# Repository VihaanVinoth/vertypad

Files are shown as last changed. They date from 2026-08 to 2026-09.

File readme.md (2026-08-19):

# VertyPad

The **VertyPad** is a custom 4x2 matrix mechanical macropad, featuring a rotary encoder, and a 0.91-inch OLED screen. It is built with the Seeed Studio XIAO RP2040 microcontroller, powered by QMK, and supports **cross-platform switching (macOS and Windows)** with an **interactive OLED UI menu**.

### PCB
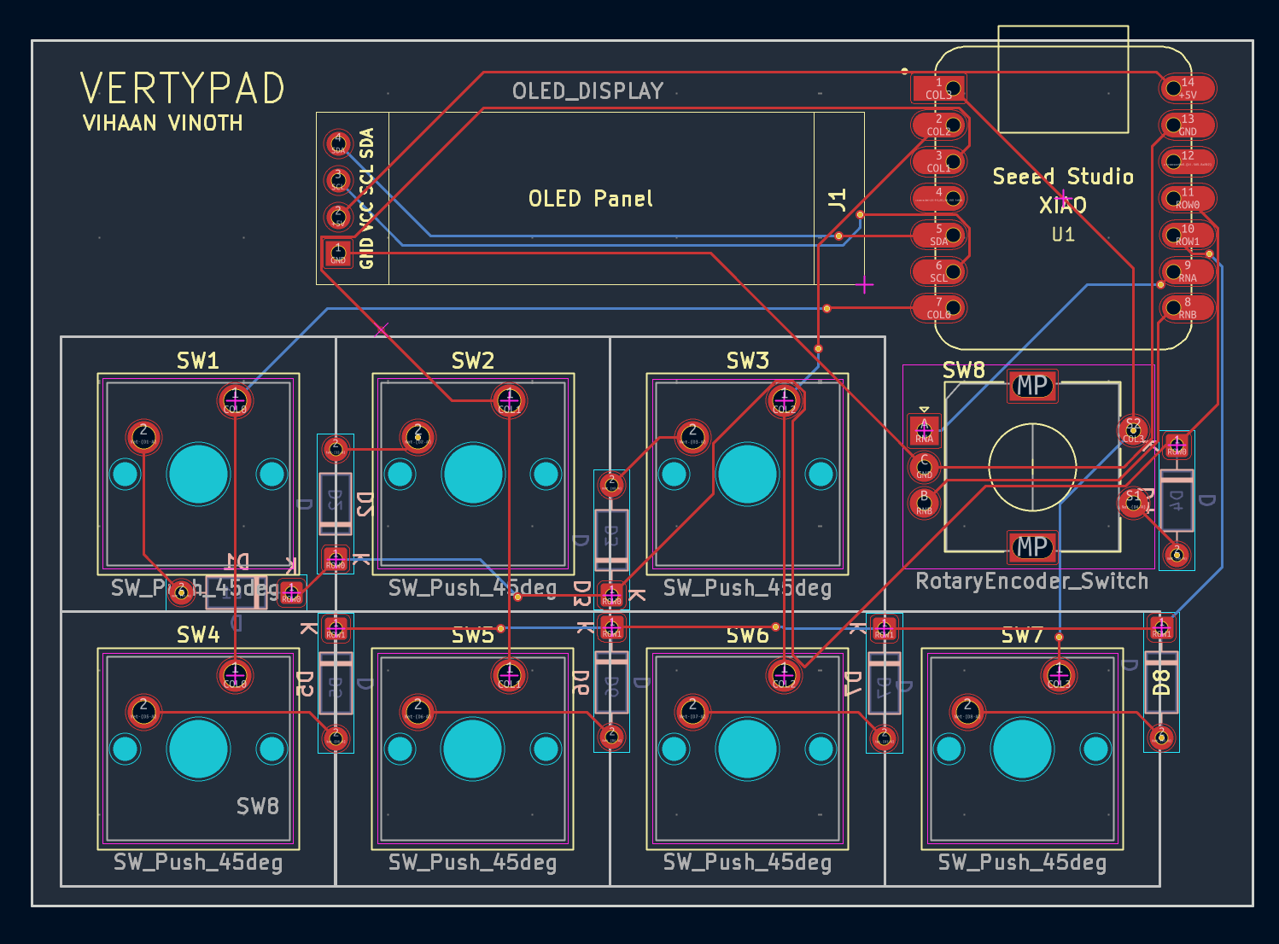
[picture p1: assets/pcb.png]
VertyPad PCB Trace Routing


### Schematics
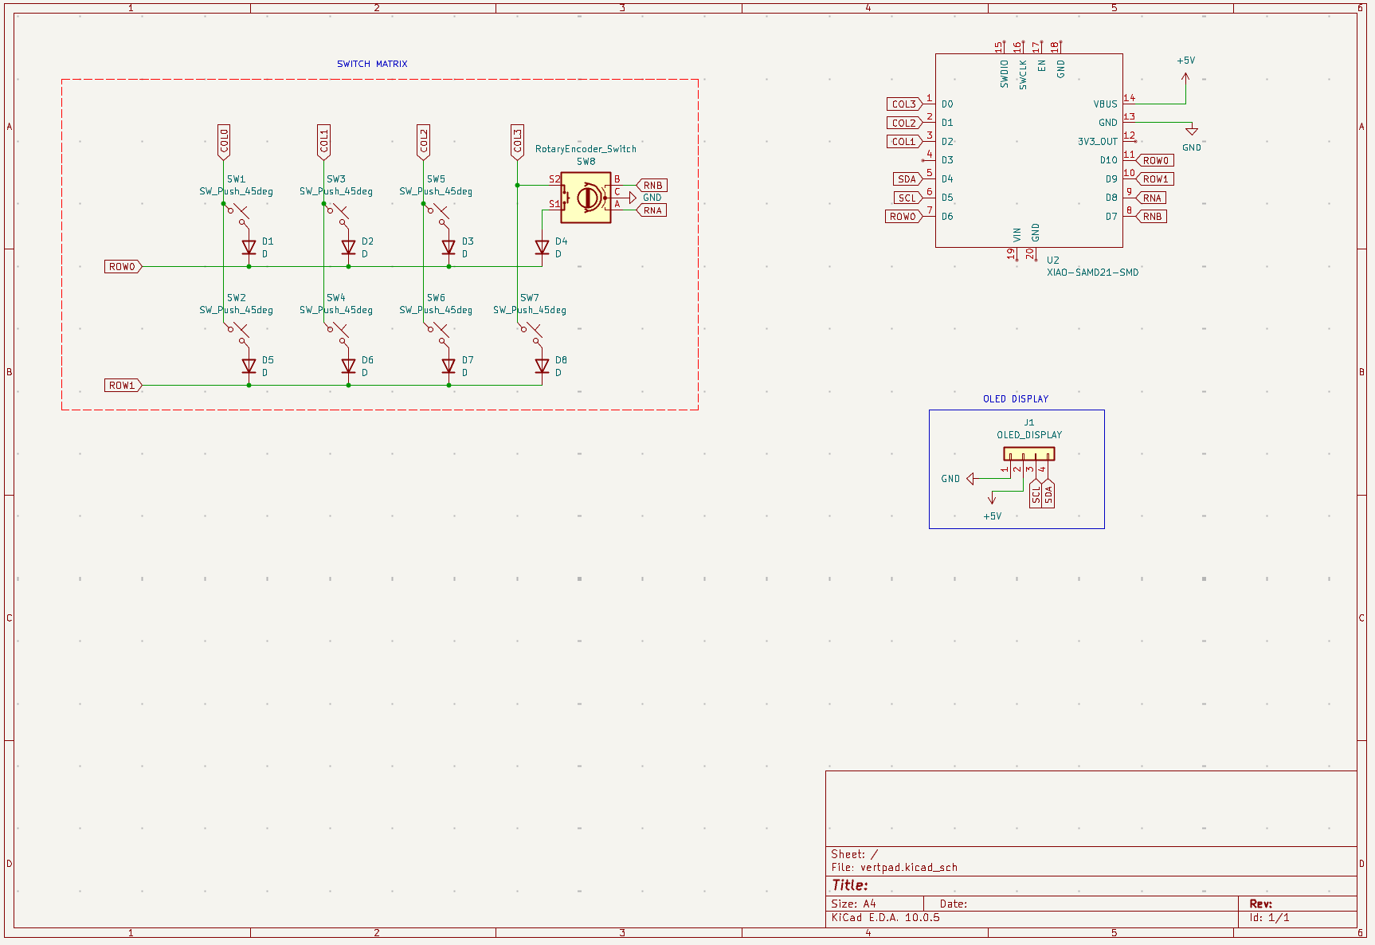
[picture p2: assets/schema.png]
VertyPad Matrix Schematic Map


### CAD
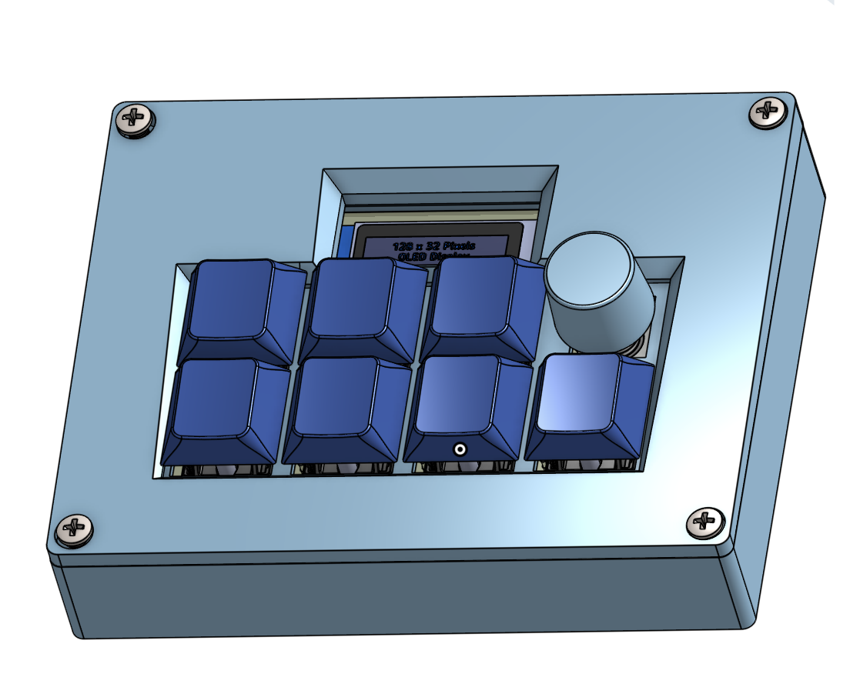
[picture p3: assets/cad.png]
VertyPad CAD


## BOM

| Component Type | Part Description | Quantity |
| :--- | :--- | :--- |
| **Microcontroller** | Seeed Studio XIAO RP2040 | 1 |
| **Switches** | Cherry MX-Style Mechanical Switches | 7 |
| **Rotary Encoder** | EC11 Rotary Encoder with Switch | 1 | 
| **Diodes** | 1N4148 Through-Hole Signal Diodes | 8 |
| **Display Panel** | 0.91-inch I2C Monochromatic OLED | 1 | 
| **Keycaps** | DSA Profile Blank Keycaps | 7 | 
| **Screws**| M3 x 16mm Screws | 4 | 
| **Case** | 3D Printed Case/Plate | 1 |
| **PCB** | A PCB | 1 |

## Keymap & Feature Profiles

The VertyPad supports various macro commands across MacOS and Windows:

* **Copy:** `Command + C` (macOS) or `Control + C` (Windows).
* **Paste:** `Command + V` (macOS) or `Control + V` (Windows).
* **Spotlight/Search:** Launches Apple Spotlight Search (`Cmd + Space`) or Windows Search (`Win + S`).
* **Lock:** Locks the screen (`Cmd + Ctrl + Q` on Mac, `Win + L` on Windows).
* **Standard Keycodes:** Standard layout keycodes (`KC_4` and `KC_6`).
* **UI Select** Interactively toggles configuration states, such as switching between macOS and Windows modes on the OLED screen.
* **Rotary Dial Turn:** Cycles forward and backward through the **OLED UI menu screens** (Dashboard, OS Config, and Hardware Status).
* **Encoder Click Button (SW8):** Instant system audio stream mute toggle (`KC_MUTE`).

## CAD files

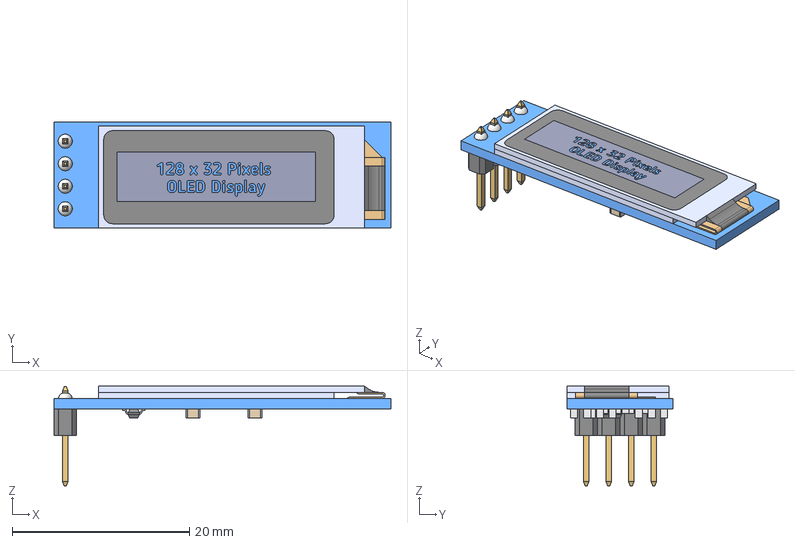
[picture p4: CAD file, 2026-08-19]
production/3D Models/OLED 128 x 32 Display Assembly.step
38.0 x 12.0 x 11.3 mm
Board_001
1x4 Male Header_001
0603 Capacitor_001
0603 Capacitor_002
0603 Capacitor_003
0603 Capacitor_004
0603 Capacitor_005
0603 Capacitor_006
0603 Capacitor_007
0603 Capacitor_008
0603 Resistor_001
0603 Resistor_002
0603 Resistor_003
0603 Resistor_004
0603 Resistor_005
Surface Mount Transistor_001

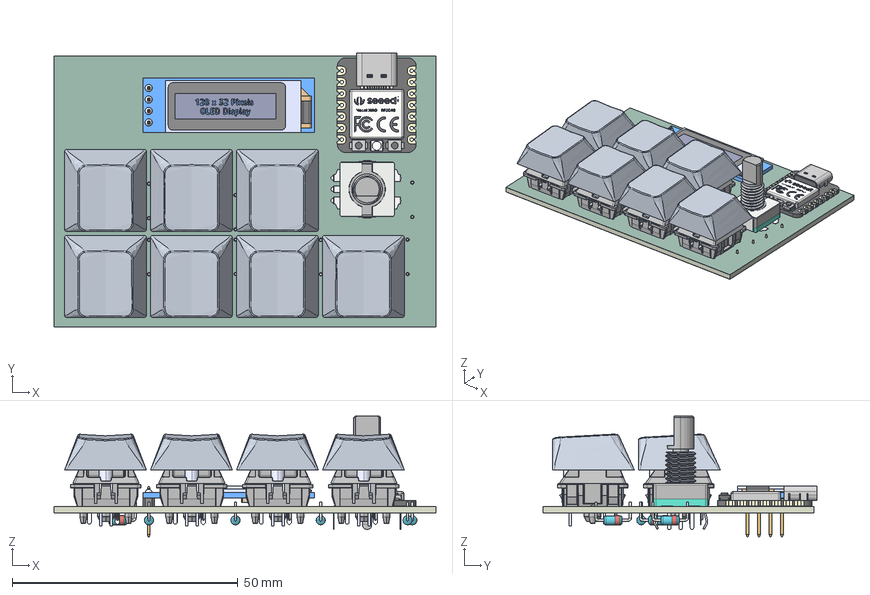
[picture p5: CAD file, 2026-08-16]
pcb/vertpad.step
84.6 x 60.6 x 26.8 mm
MX Öá °´¼ü¡ä_¨¹___¡§1 x 7
MX ס סͥ¨¢¨¬_¡§¡顧__ x 7
MXס ϞñLEDLEDLED x 7
MXÖá ÖáÌå µ×²¿ ¦Ì¡Á2__Ä¬ÈÏ_¨¢2____¨¨_ x 7
֫½ğ__Ĭɏ__¨¨_ x 7
r2_100 x 7
Board_001
1x4 Male Header_001
0603 Capacitor_001
0603 Capacitor_002
0603 Capacitor_003
0603 Capacitor_004
0603 Capacitor_005
0603 Capacitor_006
0603 Capacitor_007
0603 Capacitor_008
0603 Resistor_001
0603 Resistor_002
0603 Resistor_003
0603 Resistor_004
0603 Resistor_005
Surface Mount Transistor_001
ѽת±ძǷ
type-c v2
smd_button v3
DOUT
DIN
VSS
VDD
smd_button v3(Mirror)
D_DO-35_SOD27_P7.62mm_Horizontal x 8
vertpad_soldermask x 2
vertpad_PCB

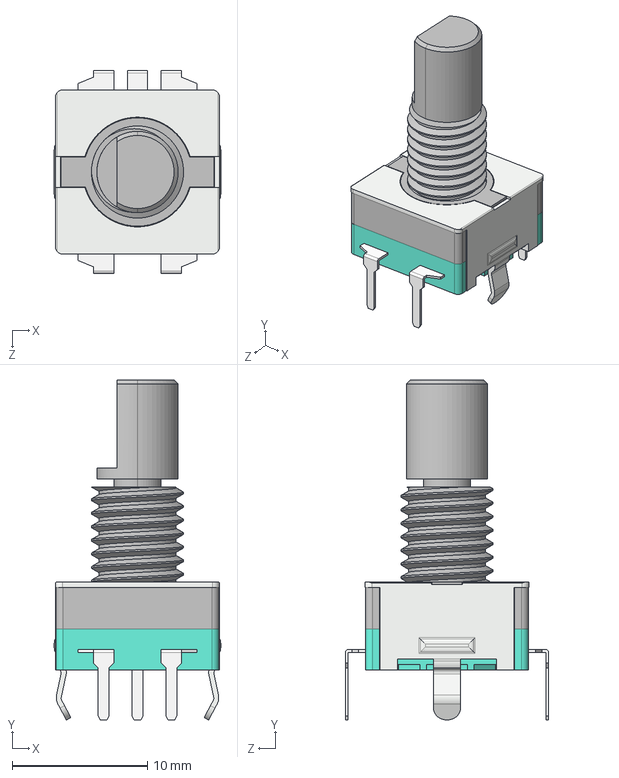
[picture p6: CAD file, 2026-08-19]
production/3D Models/encoder.step
12.3 x 25.1 x 15.0 mm

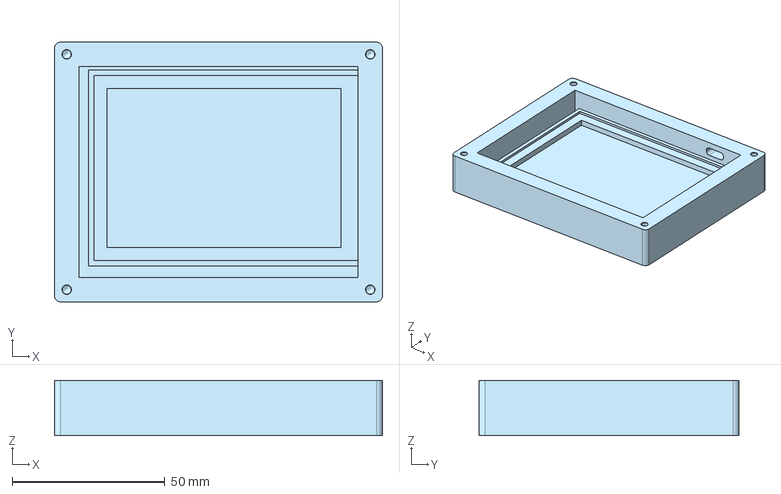
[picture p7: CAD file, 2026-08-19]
production/case.step
107.3 x 85.0 x 18.0 mm

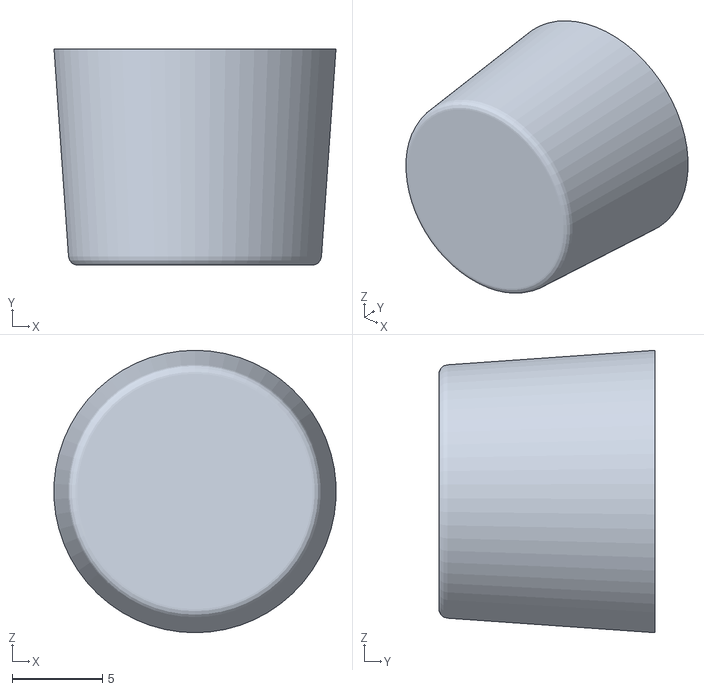
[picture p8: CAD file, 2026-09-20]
production/prints/knob.stl
15.7 x 12.0 x 15.7

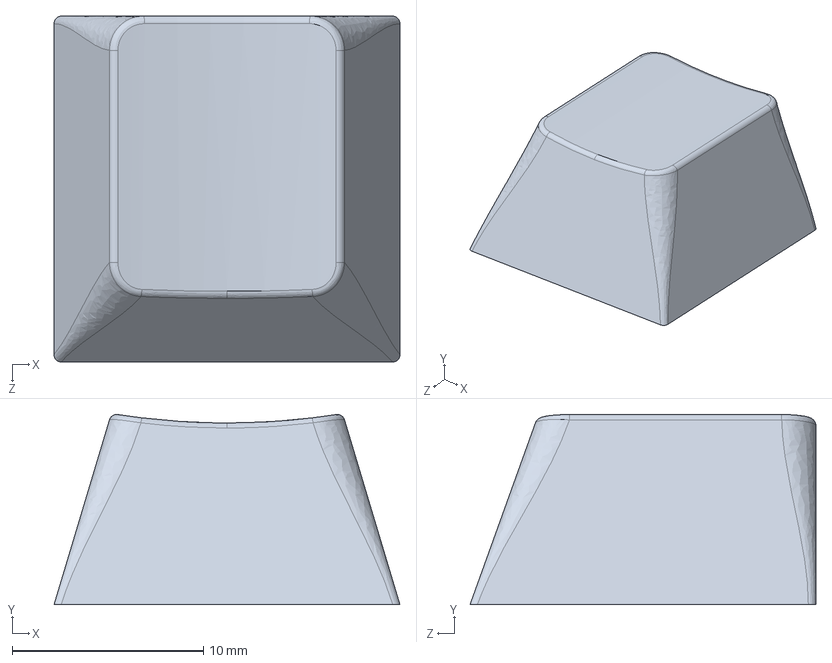
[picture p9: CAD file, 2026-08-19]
production/3D Models/r1_100.STEP
18.1 x 9.95 x 18.1 mm

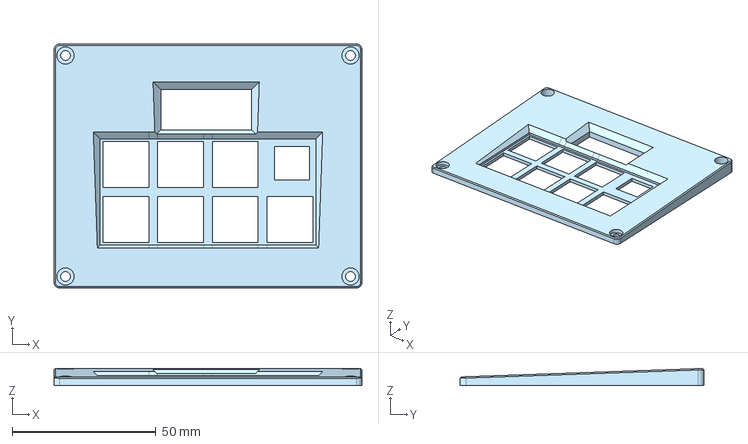
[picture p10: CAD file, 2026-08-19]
production/plate.step
107.3 x 85.0 x 5.95 mm

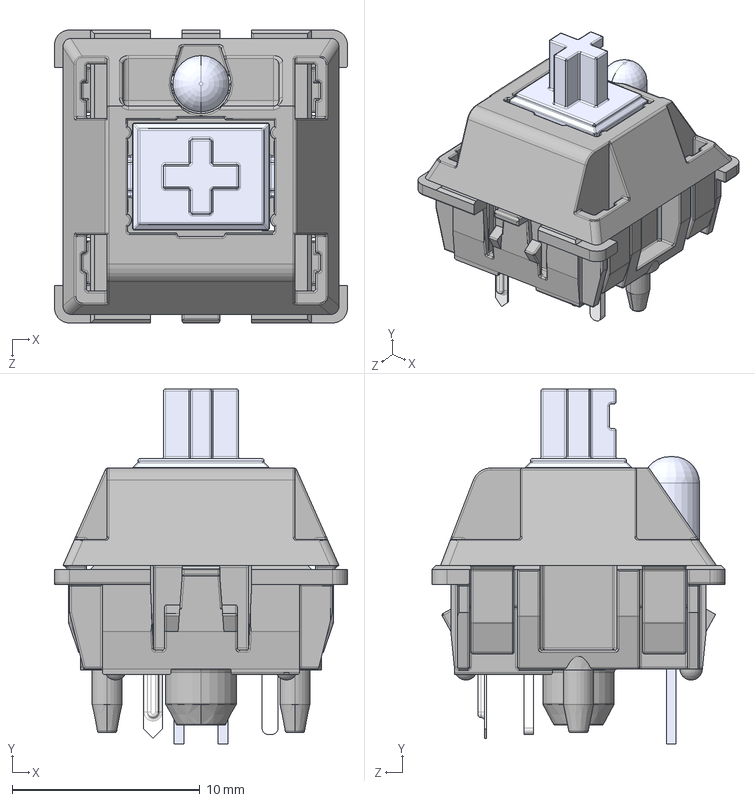
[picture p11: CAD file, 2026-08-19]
production/3D Models/mx.step
15.6 x 18.9 x 15.6 mm
MX 轴 按键′_ü___¨1
MX 轴 轴体áì_¨￠¨__
MX粣 拸簽LEDLEDLED
MX轴 轴体 底部 μ×2__默认_á2____è_
针脚___默认__è_

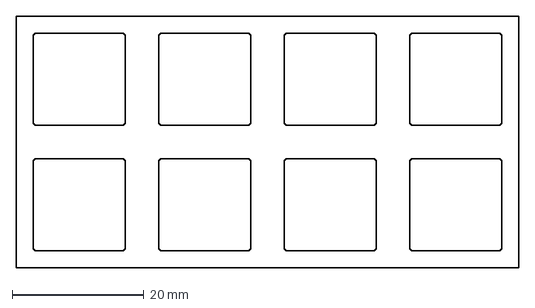
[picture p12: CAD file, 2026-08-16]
production/plate-2026-08-08T04_57_57.347Z.dxf
76.2 x 38.1 mm

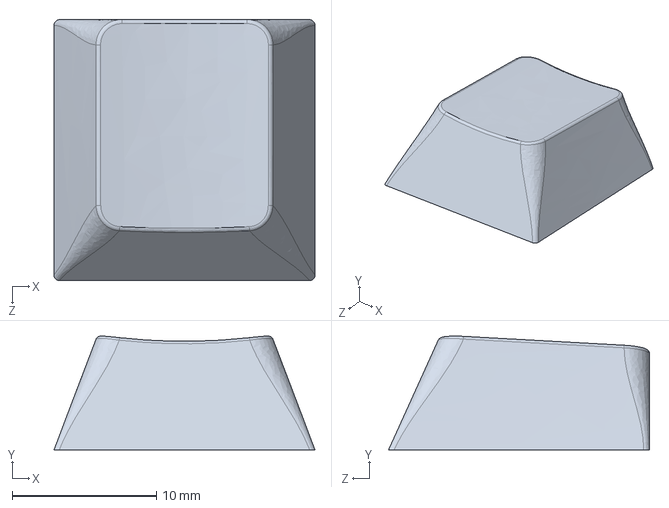
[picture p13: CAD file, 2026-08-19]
production/3D Models/r2_100.STEP
18.1 x 7.89 x 18.1 mm

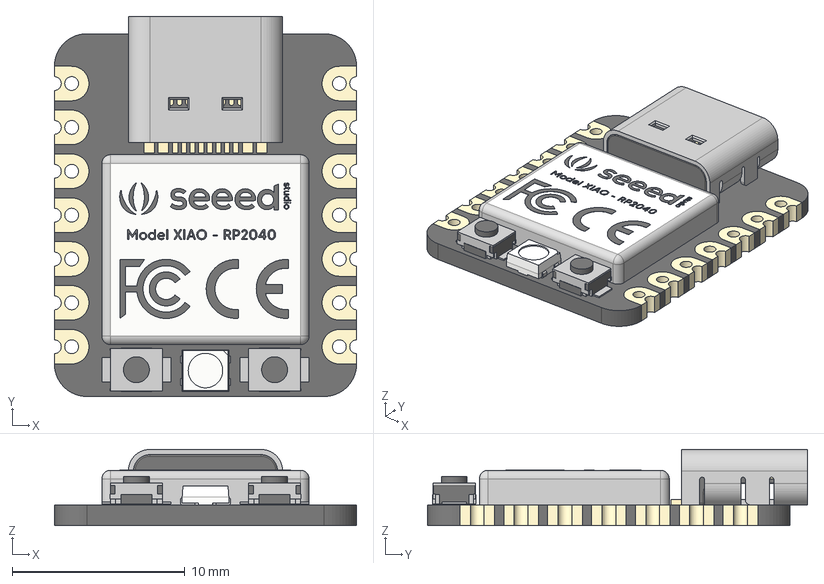
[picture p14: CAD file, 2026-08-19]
production/3D Models/Seeed Studio XIAO RP2040 v26.step
17.5 x 22.0 x 4.40 mm
type-c v2
smd_button v3
DOUT
DIN
VSS
VDD
smd_button v3(Mirror)

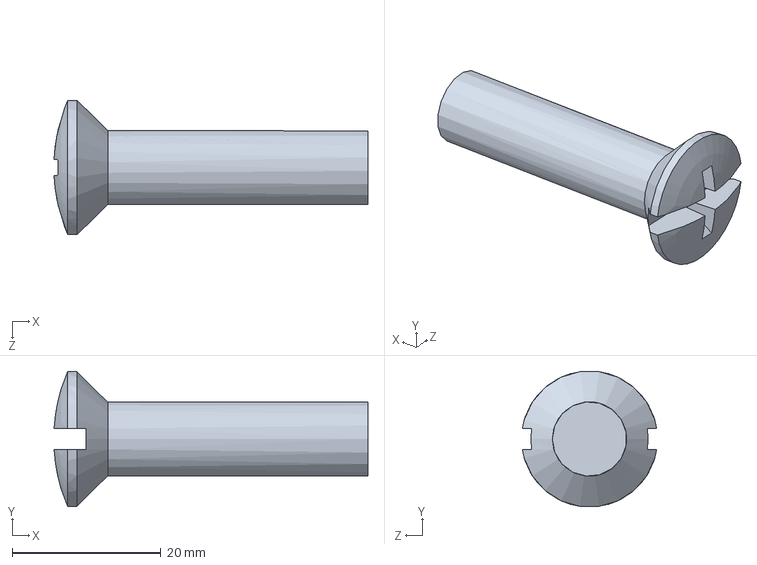
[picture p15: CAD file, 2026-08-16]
production/3D Models/m3-16mm.sldprt
42.2 x 18.2 x 18.1 mm

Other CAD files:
production/prints/case.stl
production/prints/plate.stl

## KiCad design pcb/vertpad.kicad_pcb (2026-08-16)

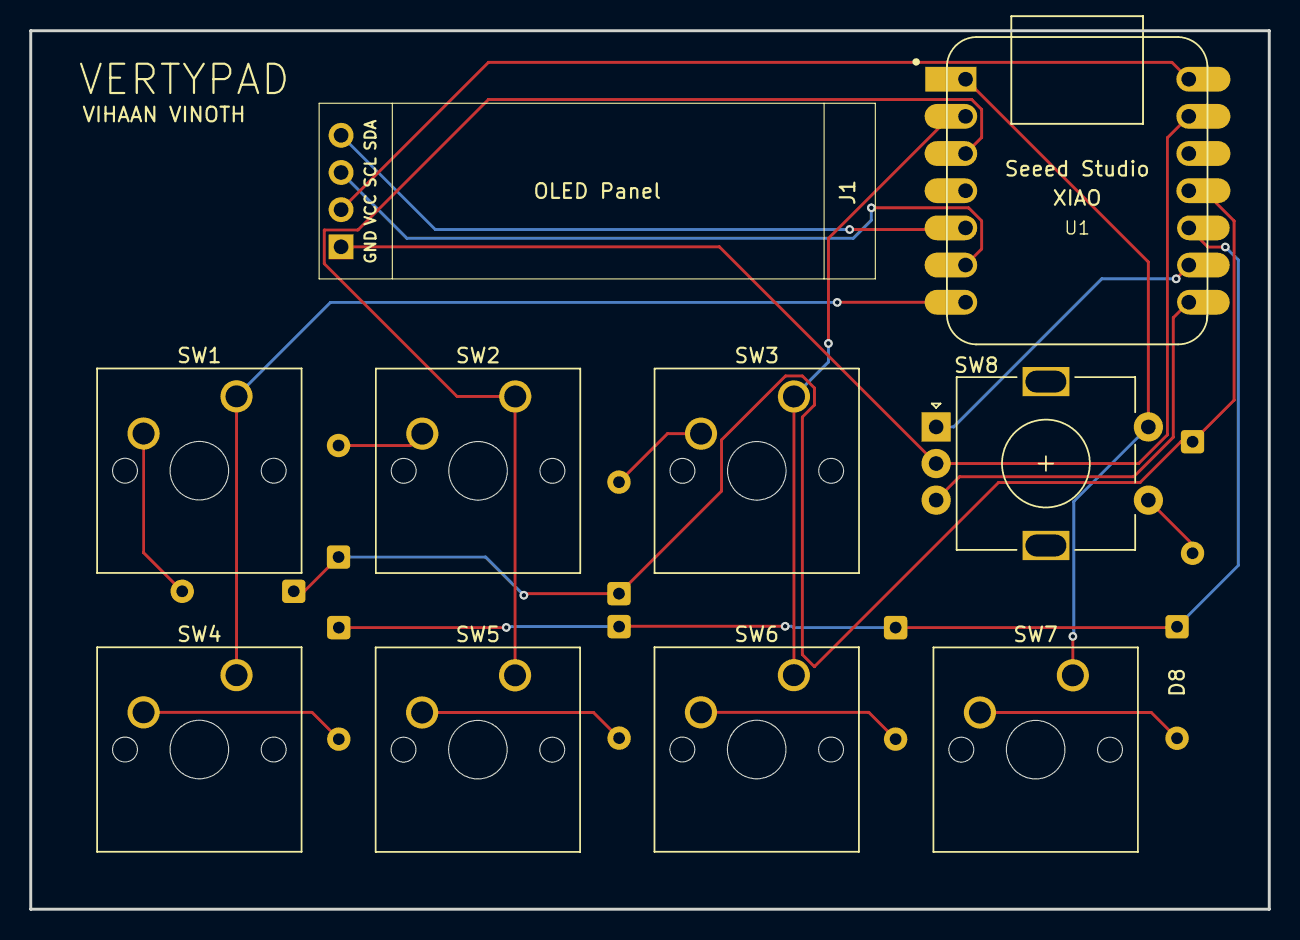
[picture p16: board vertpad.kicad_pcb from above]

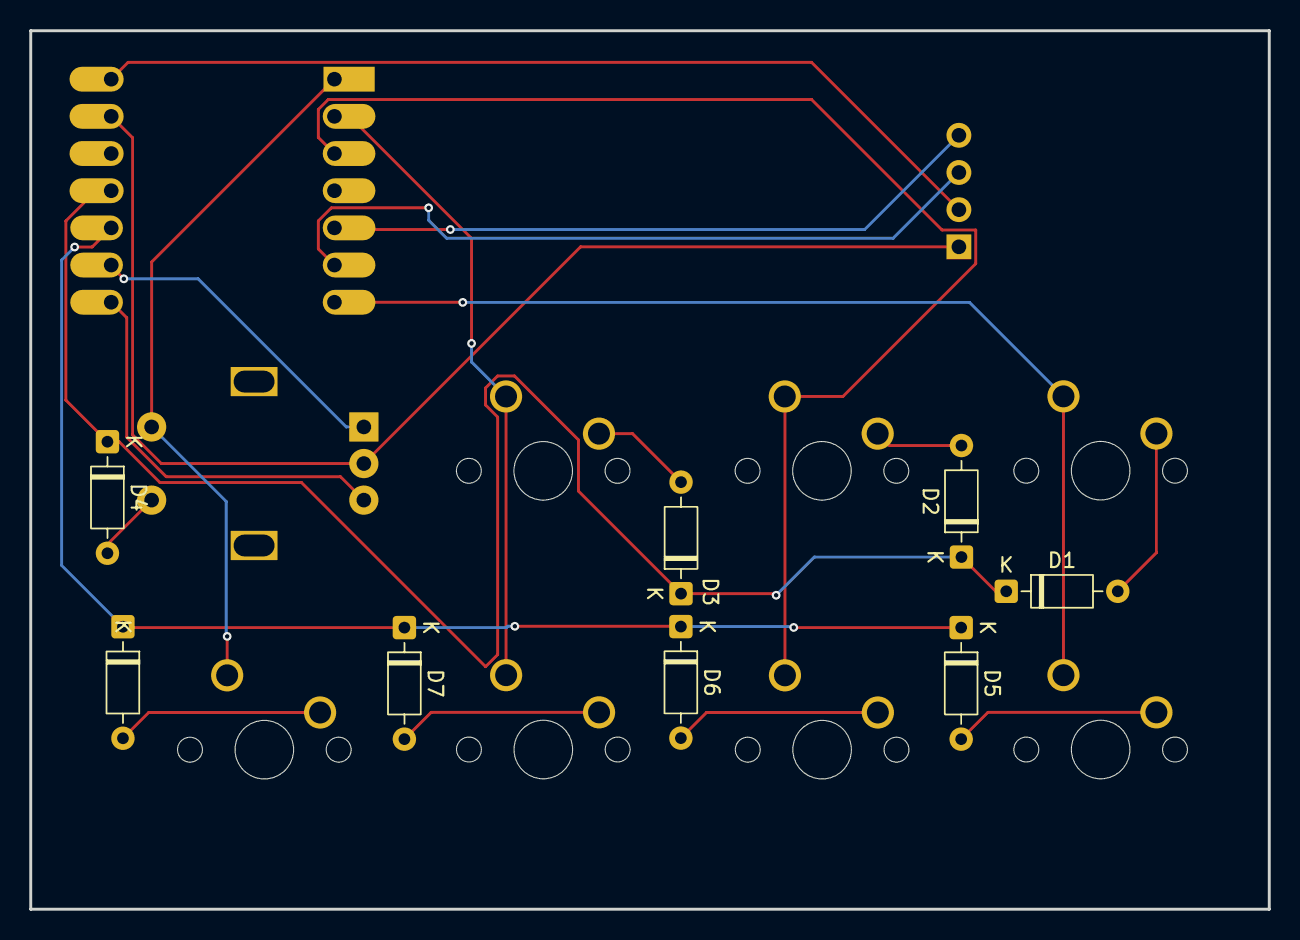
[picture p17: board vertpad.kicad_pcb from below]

Board: 2 copper layers, 84.6 x 60.0 mm, 18 parts (8 on the bottom side), 20 nets.

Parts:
D1, D2, D3, D4, D5, D6, D7, D8: D; D_DO-35_SOD27_P7.62mm_Horizontal
J1: OLED_DISPLAY; SSD1306-0.91-OLED-4pin-128x32
SW1, SW2, SW3, SW4, SW5, SW6, SW7: SW_Push_45deg; SW_Cherry_MX_1.00u_PCB
SW8: RotaryEncoder_Switch; RotaryEncoder_Alps_EC11E-Switch_Vertical_H20mm
U1: MOUDLE-SEEEDUINO-XIAO; XIAO-Generic-Hybrid-14P-2.54-21X17.8MM

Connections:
+5V: J1.2, U1.14 (5V)
COL0: SW1.1, SW4.1, U1.7 (PB08_A6_D6_TX)
COL1: SW2.1, SW5.1, U1.3 (PA10_A2_D2)
COL2: SW3.1, SW6.1, U1.2 (PA4_A1_D1)
COL3: SW7.1, SW8.S2, U1.1 (PA02_A0_D0)
GND: J1.1, SW8.C, U1.13 (GND)
unnamed: D1.2 (A), SW1.2
unnamed: D2.2 (A), SW2.2
unnamed: D3.2 (A), SW3.2
unnamed: D4.2 (A), SW8.S1
unnamed: D5.2 (A), SW4.2
unnamed: D6.2 (A), SW5.2
unnamed: D7.2 (A), SW6.2
unnamed: D8.2 (A), SW7.2
RNA: SW8.A, U1.9 (PA7_A8_D8_SCK)
RNB: SW8.B, U1.8 (PB09_A7_D7_RX)
ROW0: D1.1 (K), D2.1 (K), D3.1 (K), D4.1 (K), U1.11 (PA6_A10_D10_MOSI)
ROW1: D5.1 (K), D6.1 (K), D7.1 (K), D8.1 (K), U1.10 (PA5_A9_D9_MISO)
SCL: J1.3, U1.6 (PA9_A5_D5_SCL)
SDA: J1.4, U1.5 (PA8_A4_D4_SDA)

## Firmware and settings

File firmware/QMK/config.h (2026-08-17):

#pragma once

#define VENDOR_ID       0xFEED
#define PRODUCT_ID      0x1337
#define DEVICE_VER      0x0001

#define MATRIX_ROWS     2
#define MATRIX_COLS     4

#define OLED_DISPLAY_128X32
#define I2C1_SDA_PIN    GP6
#define I2C1_SCL_PIN    GP7

#define ENCODER_RESOLUTION 4

#define DYNAMIC_KEYMAP_EEPROM_MAX_ADDR 4095

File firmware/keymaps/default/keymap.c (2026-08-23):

// ©2026 VERTYPAD BY VIHAAN VINOTH. ALL RIGHTS RESERVED.
#include QMK_KEYBOARD_H

// UI menu screens
enum ui_screens {
    SCREEN_HOME = 0,
    SCREEN_OS_SELECT,
    SCREEN_STATUS,
    NUM_SCREENS
};

uint8_t current_screen = SCREEN_HOME;
bool is_macos_mode = true;

enum custom_keycodes {
    COPY = SAFE_RANGE,
    PASTE,
    SPOTLIGHT, // Spotlight (Mac) / Search (Win)
    LOCK,      // Lock Mac / Lock Windows (Win+L)
    UI_SELECT  // Changes settings inside the current menu (e.g., toggle OS)
};

// Row 0: SW1 (Copy), SW3 (Paste), SW5 (Spotlight), SW8 (R. Encoder - Mute)
// Row 1: SW2 (Num 4), SW4 (SW_SELECT), SW6 (Num 6), SW7 (Lock)
const uint16_t PROGMEM keymaps[][MATRIX_ROWS][MATRIX_COLS] = {
    [0] = LAYOUT(
        COPY,  PASTE,     SPOTLIGHT, KC_MUTE,
        KC_4,  UI_SELECT, KC_6,      LOCK
    )
};

// FIXED: keycode parameter updated from uint16_t to uint32_t
bool process_record_user(uint32_t keycode, keyrecord_t *record) {
    if (record->event.pressed) {
        switch (keycode) {
            case UI_SELECT:
                is_macos_mode = !is_macos_mode;
                return false;

            case COPY:
                if (is_macos_mode) {
                    SEND_STRING(SS_DOWN(X_LGUI) "c" SS_UP(X_LGUI));
                } else {
                    SEND_STRING(SS_DOWN(X_LCTL) "c" SS_UP(X_LCTL));
                }
                return false;

            case PASTE:
                if (is_macos_mode) {
                    SEND_STRING(SS_DOWN(X_LGUI) "v" SS_UP(X_LGUI));
                } else {
                    SEND_STRING(SS_DOWN(X_LCTL) "v" SS_UP(X_LCTL));
                }
                return false;

            case SPOTLIGHT:
                if (is_macos_mode) {
                    SEND_STRING(SS_DOWN(X_LGUI) SS_TAP(X_SPACE) SS_UP(X_LGUI));
                } else {
                    SEND_STRING(SS_DOWN(X_LGUI) "s" SS_UP(X_LGUI)); 
                }
                return false;

            case LOCK:
                if (is_macos_mode) {
                    SEND_STRING(SS_DOWN(X_LGUI) SS_DOWN(X_LCTL) "q" SS_UP(X_LCTL) SS_UP(X_LGUI));
                } else {
                    SEND_STRING(SS_DOWN(X_LGUI) "l" SS_UP(X_LGUI)); 
                }
                return false;
        }
    }
    return true;
}

#if defined(ENCODER_ENABLE)
// FIXED: Updated encoder signature to match modern QMK expectations
bool encoder_update_user(uint8_t index, bool clockwise) {
    if (index == 0) {
        if (clockwise) {
            current_screen = (current_screen + 1) % NUM_SCREENS;
        } else {
            current_screen = (current_screen - 1 + NUM_SCREENS) % NUM_SCREENS;
        }
    }
    return true;
}
#endif

#if defined(OLED_ENABLE)
oled_rotation_t oled_init_user(oled_rotation_t rotation) {
    return rotation;
}

// FIXED: Changed return type from bool to void, removed return statement
void oled_task_user(void) {
    oled_write_P(PSTR("== VERTYPAD ==\n"), false);

    switch (current_screen) {
        case SCREEN_HOME:
            oled_write_P(PSTR("Mode: Dashboard\n"), false);
            if (is_macos_mode) {
                oled_write_P(PSTR("OS: [macOS] Win\n"), false);
            } else {
                oled_write_P(PSTR("OS: Mac [Windows]\n"), false);
            }
            oled_write_P(PSTR("Turn wheel to menu\n"), false);
            break;

        case SCREEN_OS_SELECT:
            oled_write_P(PSTR("Menu: OS Config\n"), false);
            if (is_macos_mode) {
                oled_write_P(PSTR("> macOS (Active)\n Windows\n"), false);
            } else {
                oled_write_P(PSTR(" macOS\n> Windows (Active)\n"), false);
            }
            oled_write_P(PSTR("Press SW4 to Toggle\n"), false);
            break;

        case SCREEN_STATUS:
            oled_write_P(PSTR("Menu: Hardware\n"), false);
            oled_write_P(PSTR("Encoder: UI Nav\n"), false);
            oled_write_P(PSTR("Matrix: 2x4 Active\n"), false);
            break;
    }
}
#endif

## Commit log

2026-08-16 init commit
    [case.step, m3-16mm.sldprt, plate-2026-08-08T04_57_57.347Z.dxf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]
2026-08-19 final init
    [OLED 128 x 32 Display Assembly.step, Seeed Studio XIAO RP2040 v26.step, case.step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]
2026-08-23 move gerbers.zip
2026-09-17 add 3D print items
    [case.stl, knob.stl, plate.stl]
2026-09-20 fix stl
    [case.stl, knob.stl, plate.stl]
